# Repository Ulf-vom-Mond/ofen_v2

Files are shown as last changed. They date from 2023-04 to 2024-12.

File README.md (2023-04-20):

# Ofen v2
This is a project about building an oven for high temperatures. Included in this repository are the schematics and the layout for the control PCB and the microcontroller firmware.

## Building with Arduino IDE
You need to install the following libraries:

### LCDWiki library
This is neccessary for SPI communication with the ILI9488 LCD driver.
Follow this page for installation: http://www.lcdwiki.com/3.5inch_SPI_Module_ILI9488_SKU:MSP3520

### MiniCore
The schematic uses a bare ATMega328p without the Arduino overhead. For an effective use of all its features, you need to follow this installation guide:
https://github.com/MCUdude/MiniCore

IMPORTANT: You need to set the clock to "Internal 8 MHz". If you select anything called "external", the ATMega will not run and you cannot program it anymore.

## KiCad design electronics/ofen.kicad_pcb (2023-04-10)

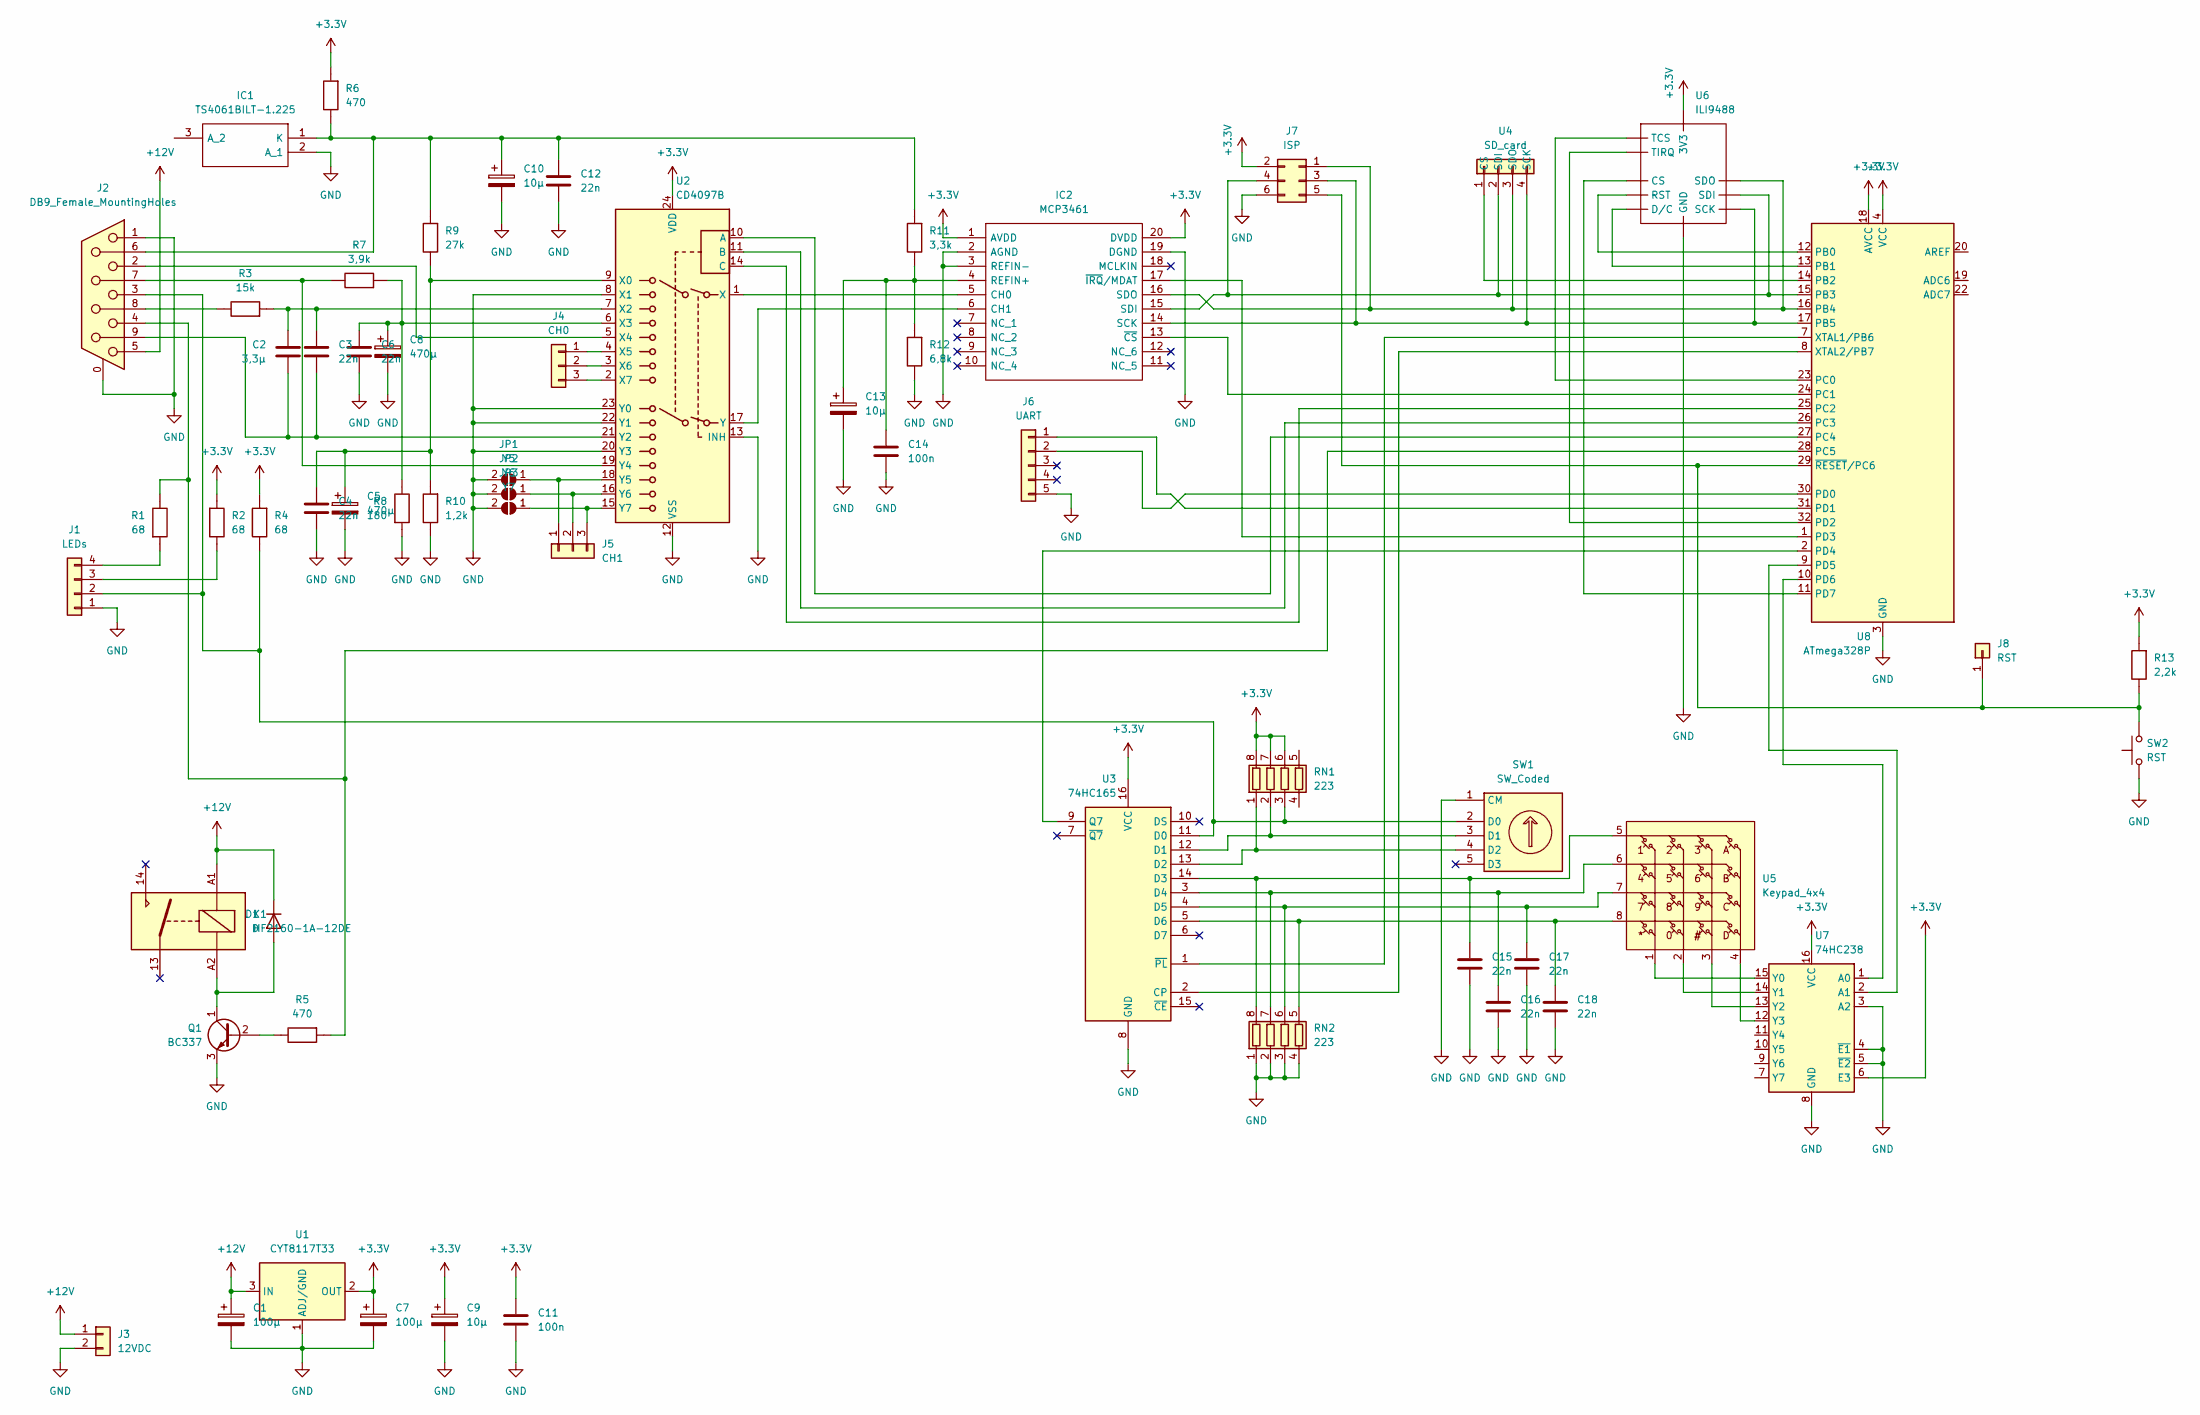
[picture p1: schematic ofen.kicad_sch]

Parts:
C1, C7: 100µ; CP_Radial_D6.3mm_P2.50mm
C2: 3,3µ; C_Rect_L7.2mm_W7.2mm_P5.00mm_FKS2_FKP2_MKS2_MKP2
C3, C4, C6, C12, C15, C16, C17, C18: 22n; C_Disc_D5.0mm_W2.5mm_P2.50mm
C5, C8: 470µ; CP_Radial_D10.0mm_P5.00mm
C9, C10, C13: 10µ; CP_Radial_Tantal_D4.5mm_P5.00mm
C11, C14: 100n; C_Rect_L10.0mm_W4.0mm_P7.50mm_MKS4
D1: D; D_A-405_P7.62mm_Horizontal
IC1: TS4061BILT-1.225; SOT-23-3; Mouser Part Number 511-TS4061BILT-1.225
IC2: MCP3461; TSSOP-20_4.4x6.5mm_P0.65mm; Mouser Part Number 579-MCP3461T-E/ST
J1: LEDs; Molex_KK-254_AE-6410-04A_1x04_P2.54mm_Vertical
J2: DB9_Female_MountingHoles; DSUB-9_Female_Horizontal_P2.77x2.84mm_EdgePinOffset7.70mm_H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
J3: 12VDC; JST_VH_B2P3-VH_1x02_P7.92mm_Vertical
J4: CH0; PinHeader_1x03_P2.54mm_Vertical
J5: CH1; PinHeader_1x03_P2.54mm_Vertical
J6: UART; PinSocket_1x05_P2.54mm_Vertical
J7: ISP; IDC-Header_2x03_P2.54mm_Vertical
J8: RST; PinHeader_1x01_P2.54mm_Vertical
JP1: Y5; SolderJumper-2_P1.3mm_Open_RoundedPad1.0x1.5mm
JP2: Y6; SolderJumper-2_P1.3mm_Open_RoundedPad1.0x1.5mm
JP3: Y7; SolderJumper-2_P1.3mm_Open_RoundedPad1.0x1.5mm
K1: HF2160-1A-12DE; Relay_SPST_RAYEX-L90AS
Q1: BC337; TO-92_Inline_Wide
R1, R2, R4: 68; R_Axial_DIN0207_L6.3mm_D2.5mm_P10.16mm_Horizontal
R3: 15k; R_Axial_DIN0207_L6.3mm_D2.5mm_P10.16mm_Horizontal
R5, R6: 470; R_Axial_DIN0207_L6.3mm_D2.5mm_P10.16mm_Horizontal
R7: 3,9k; R_Axial_DIN0207_L6.3mm_D2.5mm_P10.16mm_Horizontal
R8: 180; R_Axial_DIN0207_L6.3mm_D2.5mm_P10.16mm_Horizontal
R9: 27k; R_Axial_DIN0207_L6.3mm_D2.5mm_P10.16mm_Horizontal
R10: 1,2k; R_Axial_DIN0207_L6.3mm_D2.5mm_P10.16mm_Horizontal
R11: 3,3k; R_Axial_DIN0207_L6.3mm_D2.5mm_P10.16mm_Horizontal
R12: 6,8k; R_Axial_DIN0207_L6.3mm_D2.5mm_P10.16mm_Horizontal
R13: 2,2k; R_Axial_DIN0207_L6.3mm_D2.5mm_P10.16mm_Horizontal
RN1, RN2: 223; R_Array_Concave_4x0603
SW1: SW_Coded; Molex_Micro-Latch_53253-0470_1x04_P2.00mm_Vertical
SW2: RST; SW_Tactile_SPST_Angled_PTS645Vx83-2LFS
U1: CYT8117T33; SOT-223-3_TabPin2
U2: CD4097B; TSSOP-24_4.4x7.8mm_P0.65mm
U3: 74HC165; TSSOP-16_4.4x5mm_P0.65mm
U4: SD_card; Molex_Micro-Latch_53253-0470_1x04_P2.00mm_Vertical
U5: Keypad_4x4; Molex_Micro-Latch_53253-0870_1x08_P2.00mm_Vertical
U6: ILI9488; ribbon_1x10_horizontal
U7: 74HC238; SOP-16_3.9x9.9mm_P1.27mm
U8: ATmega328P; TQFP-32_7x7mm_P0.8mm

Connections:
+3.3V: C7.1, C9.1, C11.1, IC2.1 (AVDD), IC2.20 (DVDD), J7.2, R2.1, R4.1, R6.1, R13.1, RN1.6 (R3.2), RN1.7 (R2.2), RN1.8 (R1.2), U1.2 (OUT), U2.24 (VDD), U3.16 (VCC), U6.1 (3V3), U7.6 (E3), U7.16 (VCC), U8.4 (VCC), U8.6 (VCC), U8.18 (AVCC)
+12V: C1.1, D1.1 (K), J2.5, J3.1, K1.A1, U1.3 (IN)
GND: C1.2, C4.2, C5.2, C6.2, C7.2, C8.2, C9.2, C10.2, C11.2, C12.2, C13.2, C14.2, C15.2, C16.2, C17.2, C18.2, IC1.2 (A_1), IC2.2 (AGND), IC2.3 (REFIN-), IC2.19 (DGND), J1.1, J2.0 (PAD), J2.1, J3.2, J6.5, J7.6, JP1.2 (B), JP2.2 (B), JP3.2 (B), Q1.3 (E), R8.1, R10.2, R12.2, RN2.1 (R1.1), RN2.2 (R2.1), RN2.3 (R3.1), RN2.4 (R4.1), SW1.1 (CM), SW2.1, U1.1 (ADJ/GND), U2.8 (X1), U2.12 (VSS), U2.13 (INH), U2.20 (Y3), U2.22 (Y1), U2.23 (Y0), U3.8 (GND), U6.2 (GND), U7.3 (A2), U7.4 (~E1), U7.5 (~E2), U7.8 (GND), U8.3 (GND), U8.5 (GND), U8.21 (GND)
unnamed: C2.1, C3.2, J2.9, U2.21 (Y2)
unnamed: C2.2, C3.1, R3.1, U2.7 (X2)
unnamed: C4.1, C5.1, R9.2, R10.1, U2.9 (X0)
unnamed: C6.1, C8.1, R7.1, R8.2, U2.6 (X3)
unnamed: C10.1, C12.1, IC1.1 (K), J2.6, R6.2, R9.1, R11.1
unnamed: C13.1, C14.1, IC2.4 (REFIN+), R11.2, R12.1
unnamed: C15.1, RN2.8 (R1.2), U3.14 (D3), U5.5
unnamed: C16.1, RN2.7 (R2.2), U3.3 (D4), U5.6
unnamed: C17.1, RN2.6 (R3.2), U3.4 (D5), U5.7
unnamed: C18.1, RN2.5 (R4.2), U3.5 (D6), U5.8
unnamed: D1.2 (A), K1.A2, Q1.1 (C)
unnamed: IC2.5 (CH0), U2.1 (X)
unnamed: IC2.6 (CH1), U2.17 (Y)
unnamed: IC2.14 (SCK), J7.3, U4.4 (SCK), U6.7 (SCK), U8.17 (PB5)
unnamed: IC2.15 (SDI), J7.4, U4.2 (SDI), U6.6 (SDI), U8.15 (PB3)
unnamed: IC2.16 (SDO), J7.1, U4.3 (SDO), U6.8 (SDO), U8.16 (PB4)
unnamed: IC2.17 (~IRQ/MDAT), U8.1 (PD3)
unnamed: J1.3, R2.2
unnamed: J1.4, R1.1
unnamed: J2.2, U2.5 (X4)
unnamed: J2.4, R1.2, R5.1, U8.28 (PC5)
unnamed: J2.7, R7.2, U2.19 (Y4)
unnamed: J2.8, R3.2
unnamed: J4.1, U2.4 (X5)
unnamed: J4.2, U2.3 (X6)
unnamed: J4.3, U2.2 (X7)
unnamed: J5.1, JP1.1 (A), U2.18 (Y5)
unnamed: J5.2, JP2.1 (A), U2.16 (Y6)
unnamed: J5.3, JP3.1 (A), U2.15 (Y7)
unnamed: J6.1, U8.31 (PD1)
unnamed: J6.2, U8.30 (PD0)
unnamed: J7.5, J8.1, R13.2, SW2.2, U8.29 (~RESET/PC6)
unnamed: Q1.2 (B), R5.2
unnamed: RN1.2 (R2.1), SW1.3 (D1), U3.12 (D1)
unnamed: J1.2, J2.3, R4.2, RN1.3 (R3.1), SW1.2 (D0), U3.11 (D0)
unnamed: RN1.1 (R1.1), SW1.4 (D2), U3.13 (D2)
unnamed: U5.1, U7.15 (Y0)
unnamed: U5.2, U7.14 (Y1)
unnamed: U5.3, U7.13 (Y2)
unnamed: U5.4, U7.12 (Y3)
unnamed: U6.3 (CS), U8.11 (PD7)
unnamed: U6.10 (TIRQ), U8.32 (PD2)
unnamed: U3.9 (Q7), U8.2 (PD4)
unnamed: U3.1 (~PL), U8.7 (XTAL1/PB6)
unnamed: U3.2 (CP), U8.8 (XTAL2/PB7)
unnamed: U7.2 (A1), U8.9 (PD5)
unnamed: U7.1 (A0), U8.10 (PD6)
unnamed: U6.4 (RST), U8.12 (PB0)
unnamed: U6.5 (D/C), U8.13 (PB1)
unnamed: U4.1 (CS), U8.14 (PB2)
unnamed: U6.9 (TCS), U8.23 (PC0)
unnamed: IC2.13 (~CS), U8.24 (PC1)
unnamed: U2.14 (C), U8.25 (PC2)
unnamed: U2.11 (B), U8.26 (PC3)
unnamed: U2.10 (A), U8.27 (PC4)

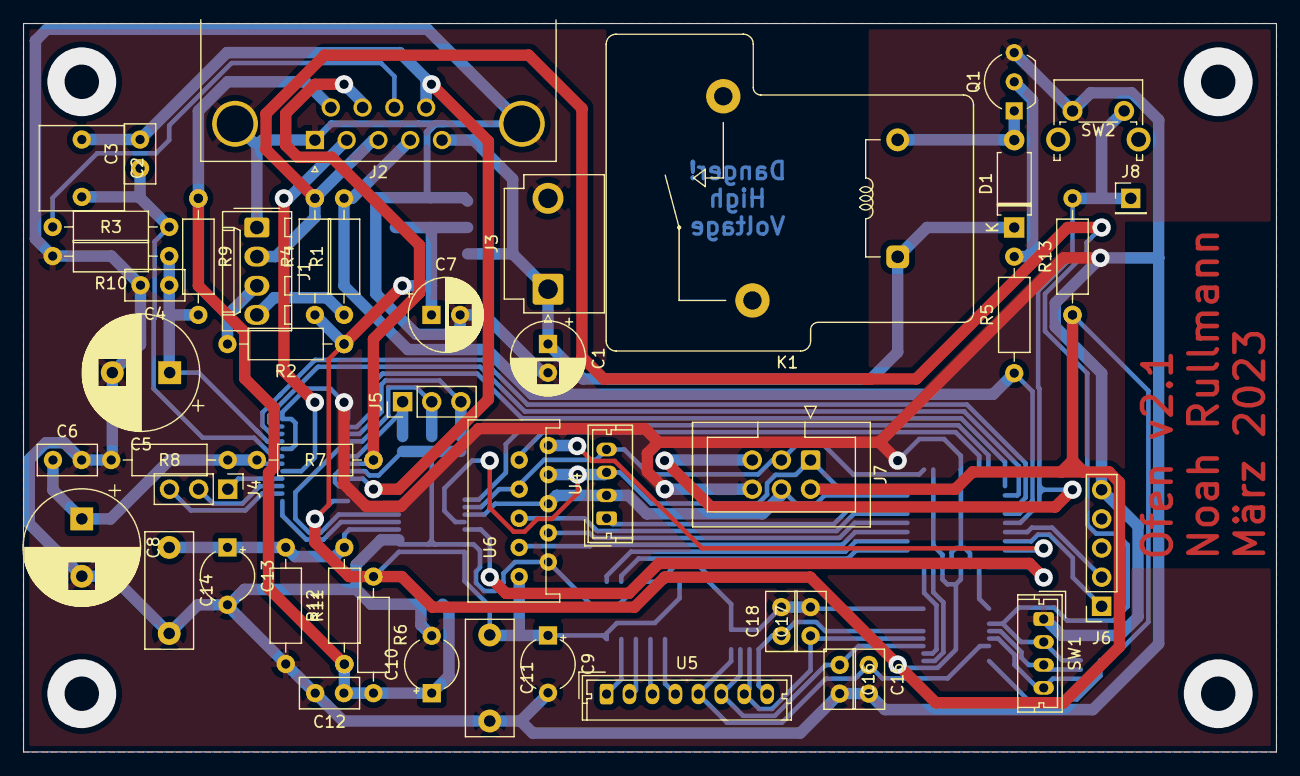
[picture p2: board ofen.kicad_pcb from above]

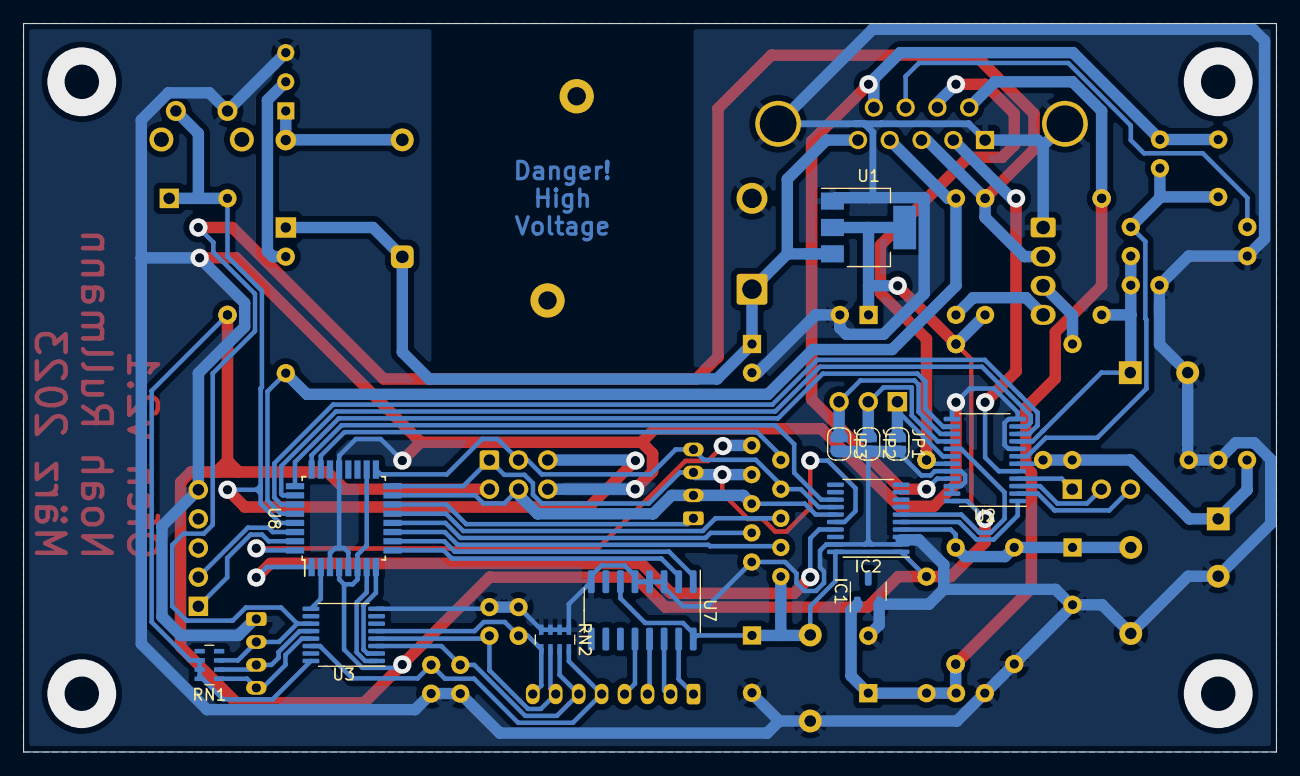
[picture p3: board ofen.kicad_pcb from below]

Board: 2 copper layers, 109.2 x 63.5 mm, 59 parts (12 on the bottom side), 58 nets.

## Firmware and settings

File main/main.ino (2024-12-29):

#include <SPI.h>
#include "temperature.h"
#include "user_input.h"
#include "user_interface.h"
#include "pins.h"
#include "avrio.h"
#include "adc.h"
#include "list.h"
#include "keypad.h"
#include "timer.h"
#include "mux.h"

#define BUF_LEN 10
#define MUX_MAX_CH 3

// void key_event_listener(uint16_t keys) {
//   Serial.println((keys), BIN);
// }

char data_ready = 1;
uint8_t mux_state = 0;
uint8_t buf_state = 0;

int16_t adc_buf[8][BUF_LEN] = {0};

void adc_callback(int16_t data, uint8_t invalid) {
  data_ready = 1;
  if(invalid) return;
  adc_buf[mux_state][buf_state] = data;
  // Serial.println(adc_buf[mux_state][buf_state]);
  mux_state++;
  if(mux_state > MUX_MAX_CH) {
    mux_state = 0;
    buf_state++;
    if(buf_state >= BUF_LEN) buf_state = 0;
  }
  // Serial.println("adc called back!");
}

void tmr_evnt_lstnr1(void *params) {
  // Serial.println(get_voltage(THERMISTOR_CH), 5);
  // Serial.print("Thermistor: ");
  // Serial.print(get_thermistor_temp());
  // Serial.println(" C");
  // Serial.print("Thermocouple: ");
  // Serial.print(get_thermocouple_temp());
  // Serial.println(" C");
  // Serial.print("Temperature: ");
  // Serial.print(get_temp());
  // Serial.println(" C");
  // select_mux_channel(REF_CH);
  // Serial.println(convert());
  // select_mux_channel(GND_CH);
  // Serial.println(convert());
  // select_mux_channel(THERMISTOR_CH);
  // Serial.println(convert());
  //delay(5000);
  // Serial.println();
  //get_thermistor_temp();

  int32_t adc_buf_avg[8] = {0};
  for(uint8_t j = 0; j<=MUX_MAX_CH; j++) {
    // Serial.print("Channel ");
    // Serial.print(j);
    // Serial.print(": ");
    for(uint8_t i = 0; i<BUF_LEN; i++) {
      adc_buf_avg[j] += adc_buf[j][i];
      // Serial.print(adc_buf[j][i]);
      // Serial.print(", ");
    }
    // Serial.println();
    adc_buf_avg[j] /= BUF_LEN;
    // Serial.println(adc_buf_avg[j]);
  }
  // Serial.print(adc_to_voltage(adc_buf_avg[THERMISTOR_CH], adc_buf_avg[GND_CH], adc_buf_avg[REF_CH]), 5);
  float temp = thermistor_voltage_to_temp(adc_to_voltage(adc_buf_avg[THERMISTOR_CH], adc_buf_avg[GND_CH], adc_buf_avg[REF_CH]));
  if(temp != temp) {
    Serial.print("GND: ");
    Serial.println(adc_buf_avg[GND_CH]);
    // Serial.print(", REF: ");
    // Serial.print(adc_buf_avg[REF_CH]);
    // Serial.print(", REF: ");
    // Serial.print(adc_buf_avg[REF_CH]);
    // Serial.print(", Thermistor: ");
    // Serial.println(adc_buf_avg[THERMISTOR_CH]);
    for(uint8_t i = 0; i<BUF_LEN; i++) {
      Serial.print(adc_buf[GND_CH][i]);
      Serial.print(", ");
    }
    Serial.println();
  }
  Serial.print("Thermistor: ");
  Serial.print(temp);
  Serial.println(" C");
  Serial.print("Thermocouple: ");
  Serial.print(thermocouple_voltage_to_temp(adc_to_voltage(adc_buf_avg[THERMOCOUPLE_CH], adc_buf_avg[GND_CH], adc_buf_avg[REF_CH])));
  Serial.println(" C");
  Serial.println();
  update_status(temp);

  return;
  // data_ready = 0;
  // convert_async(adc_callback);
  // // adc_callback(convert());
  // Serial.println("trigger conversion");

  // write(ADC_CS_PIN, LOW);
  // Serial.println(SPI.transfer(DEVICE_ADDRESS << 6 | 0b00000001), BIN);
  // write(ADC_CS_PIN, HIGH);
  

  // write(ADC_IRQ_PIN, 0);
  // delay(1);
  // write(ADC_IRQ_PIN, 1);
  // data_ready = 1;
  // Serial.print("Temperature: ");
  // Serial.print(get_temp());
  // Serial.println(" C");
}

void tmr_evnt_lstnr5(void *params) {
  Serial.println("5sec");
}

void setup() {
  pin_config();

  Serial.begin(115200);
  delay(10);
  Serial.println("Hello!");
  write(ADC_CS_PIN, HIGH);
  SPI.beginTransaction(SPISettings(4000000, MSBFIRST, SPI_MODE0));

  adc_config();
  timer_config();
  sei();

  add_timer_event_listener(tmr_evnt_lstnr1, 1, 0);
  // add_timer_event_listener(tmr_evnt_lstnr5, 5, 0);

  // add_event_listener((void* (*)(uint16_t))&key_event_listener);

  // TCNT1 = 206;
  // TCCR1A =0x00;
	// TCCR1B |= (1<<CS01);		
	// TIMSK1 |= (1<<TOIE1);		// enable timer overflow interrupt
	// sei();

  launch_ui();
  write(MUX_C_PIN, 0);
  Serial.println(read(MUX_C_PIN), BIN);
  write(MUX_C_PIN, 1);
  Serial.println(read(MUX_C_PIN), BIN);
  write(MUX_C_PIN, 0);
  Serial.println(read(MUX_C_PIN), BIN);
  write(MUX_C_PIN, 1);
  Serial.println(read(MUX_C_PIN), BIN);
  write(MUX_C_PIN, 0);
  Serial.println(read(MUX_C_PIN), BIN);
}

void loop() {
  emit_key_events();
  emit_timer_events();
  if(data_ready) {
    select_mux_channel(mux_state);
    // select_mux_channel(THERMISTOR_CH);
    data_ready = 0;
    convert_async(adc_callback);
    // adc_callback(convert());
    // Serial.println("trigger conversion");
  }
  //Serial.print(".");
  // if(read(ADC_IRQ_PIN) == 0) Serial.println("IRQ Pin Low");
  // delay(1000);
  // Serial.println(get_voltage(0));
  // Serial.println(get_voltage(0), 5);
  // Serial.println("GND_CH");
  // select_mux_channel_delay(GND_CH, 0);
  // for(uint8_t i = 0; i<30; i++) {
  //   Serial.println(convert());
  //   //delay(13);
  // }
  // Serial.println("REF_CH");
  // select_mux_channel_delay(REF_CH, 0);
  // for(uint8_t i = 0; i<30; i++) {
  //   Serial.println(convert());
  //   //delay(13);
  // }
  // delay(10);
  // select_mux_channel(REF_CH);
  // delay(5000);
  // select_mux_channel(THERMISTOR_CH);
  // delay(5000);
}

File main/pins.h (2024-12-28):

#pragma once

#define IN  0
#define OUT 1

void pin_config();

// Pin definitions

// AVR pins get a number assigned according to the following scheme:
// The second decimal digit corresponds to the Port, starting at 0 for PORTA
// The first decimal digit corresponds to the Pin going from 0 thru 7
// Examples: PB5 is 15, PD6 is 36

// SD Card:
#define SD_CS_PIN       12 // PB2
#define SD_CS_DDR       OUT

// ILI9488 LCD:
#define LCD_CS_PIN      37 // PD7
#define LCD_CS_DDR      OUT
#define LCD_RST_PIN     10 // PB0
#define LCD_RST_DDR     OUT
#define LCD_DC_PIN      11 // PB1
#define LCD_DC_DDR      OUT

// XPT2046 Touch Controller:
#define TOUCH_CS_PIN    20 // PC0
#define TOUCH_CS_DDR    OUT
#define TOUCH_IRQ_PIN   32 // PD2
#define TOUCH_IRQ_DDR   IN

// MCP3461 ADC:
#define ADC_CS_PIN      21 // PC1
#define ADC_CS_DDR      OUT
#define ADC_IRQ_PIN     33 // PD3
#define ADC_IRQ_DDR     IN

// CD4097 Multiplexer:
#define MUX_A_PIN       24 // PC4
#define MUX_A_DDR       OUT
#define MUX_B_PIN       23 // PC3
#define MUX_B_DDR       OUT
#define MUX_C_PIN       22 // PC1
#define MUX_C_DDR       OUT

// CD4017 Demultiplexer:
#define DEMUX_A0_PIN    36 // PD6
#define DEMUX_A0_DDR    OUT
#define DEMUX_A1_PIN    35 // PD5
#define DEMIX_A1_DDR    OUT

// 74HC165 Shift Register:
#define SHIFT_Q_PIN     34 // PD4
#define SHIFT_Q_DDR     IN
#define SHIFT_CLK_PIN   17 // PB7
#define SHIFT_CLK_DDR   OUT
#define SHIFT_LOAD_PIN  16 // PB6
#define SHIFT_LOAD_DDR  OUT

// Heater Relais:
#define HEATER_PIN      25 // PC5
#define HEATER_DDR      OUT


// SPI:
#define MISO_PIN      14  
#define MISO_DDR      IN
#define MOSI_PIN      13
#define MOSI_DDR      OUT
#define SCK_PIN       15
#define SCK_DDR       OUT

// UART:
#define RX_PIN        30
#define RX_DDR        IN
#define TX_PIN        31
#define TX_DDR        OUT

// RESET
#define RST_PIN       26
#define RST_DDR       IN

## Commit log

2023-04-10 initial commit including version 2 of the oven PCB
    [ofen.kicad_pcb, ofen.kicad_sch]
2023-04-10 updated to version 2.1 of the pcb and added the first steps of the firmware
    [ofen.kicad_sch]
2023-09-13 temperature table editing
    [ofen.kicad_pcb]
2024-12-21 something changed with the kicad files?
2024-12-26 fixed adc issues, thermistor measurement works well now, still work to do with thermocouple
    [ofen.kicad_sch]
2024-12-28 asynchronous thermistor measurement works in most of the cases
2024-12-28 thermistor measurement works perfectly
2024-12-28 thermocouple temperature calculation seems to work, but some problem is still present
2024-12-29 print thermistor temperature to lcd
